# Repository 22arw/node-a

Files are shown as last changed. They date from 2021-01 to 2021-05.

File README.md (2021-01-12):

# Node-A Cruiser Maintenance Management for Wichita
## About this project
This project will improve cruiser maintenance tracking for the Wichita Police department. To better maintain our Wichita Police cruisers, an OBD-II compatible device connects to and monitors each cruiser. The device utilizes a LoRaWAN network within Wichita to send realtime notifications and data through gateways to a central server which can then be displayed on dashboards for the department. In order to utilize the LoRaWAN network, we’ll make use of the Protocol Buffers method of serializing data into small packets. We may divide the data into multiple packets sent periodically to meet the LoRaWAN duty cycle standard. Once the Server group has set up a network server, we’ll work to create a windows application that will display statistics from all cruisers and notify the maintenance department when maintenance is due. 
## Pinout
The pinout for the MKRCAN sheild, Adafruit Feather 32u4, ODB2 connector, and LED is listed below.

| DESC | MKRCAN | Feather | ODB2 | LED |
|---|---|---|---|-----|
| CAN CS | 3 | 6 | | |
| INT | 7 | SDA(1) | | |
| MOSI | 8 | MO | | |
| SCK | 9 | SCK | | |
| MISO | 10 | MI | | |
| CPU POWER | vcc | 3v | | |
| POWER TO F | vin | usb | | |
| POWER FROM F | 5v | usb | | |
| GND | GND | GND | | |
| LED GND | | GND | | GND |
| Red | | 9 | | R |
| Green | | 10 | | G |
| Blue | | 11 | | B |
| POWER FROM CAR | | 16 | VIN  | |
| CAR CAN | | 6 (CANH)  | CANL | |
| CAR CAN | | 14 (CANL) | CANH | |
| GND | | 5 | GND  | |

*The CAN library uses default CS and INT pins. To set different pins, use CAN.setPins(CS, INT).*

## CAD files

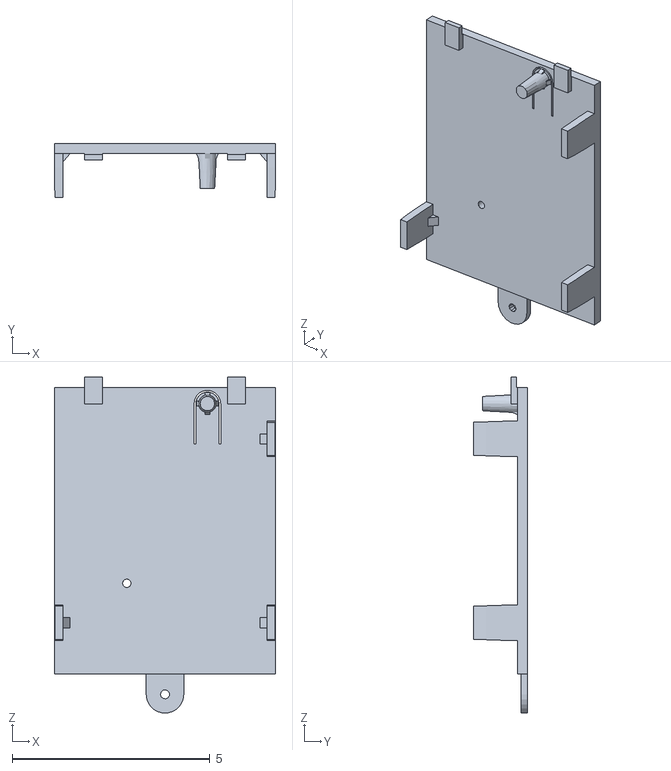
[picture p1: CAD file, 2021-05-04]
Inventor/housing.v.2.1/Top.stl
5.59 x 1.37 x 8.49

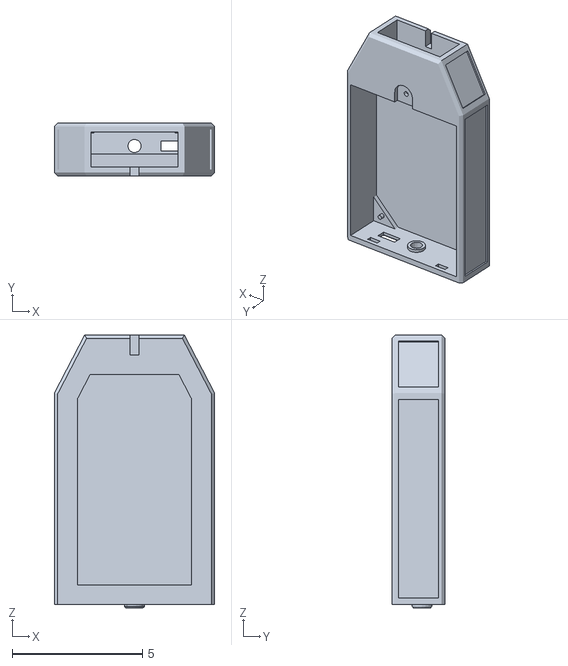
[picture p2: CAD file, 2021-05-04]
Inventor/housing.v.2.1/Bottom.stl
6.16 x 2.03 x 10.5

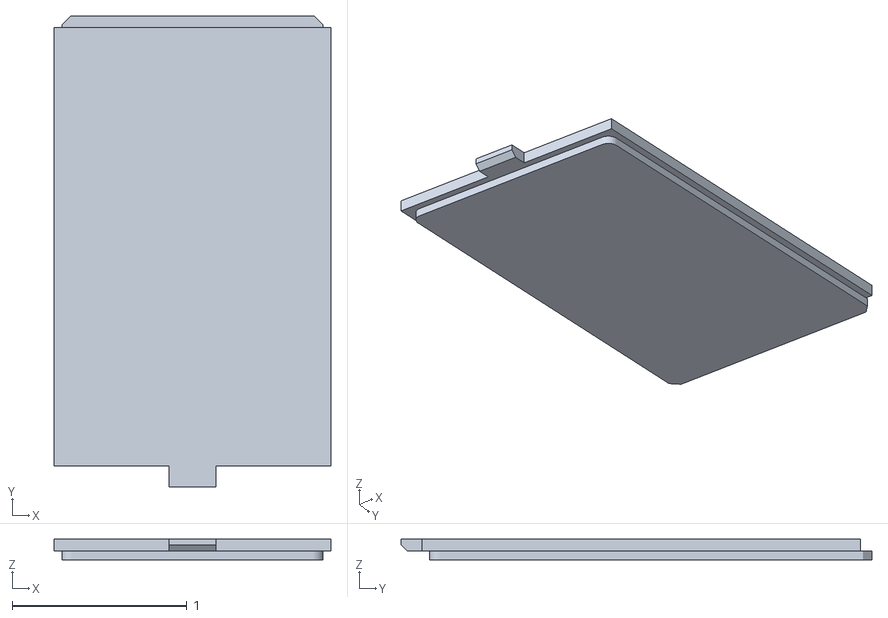
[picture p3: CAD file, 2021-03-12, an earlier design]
Inventor/housing.v.1/Main_Housing_Cap.stl
1.58 x 2.69 x 0.119

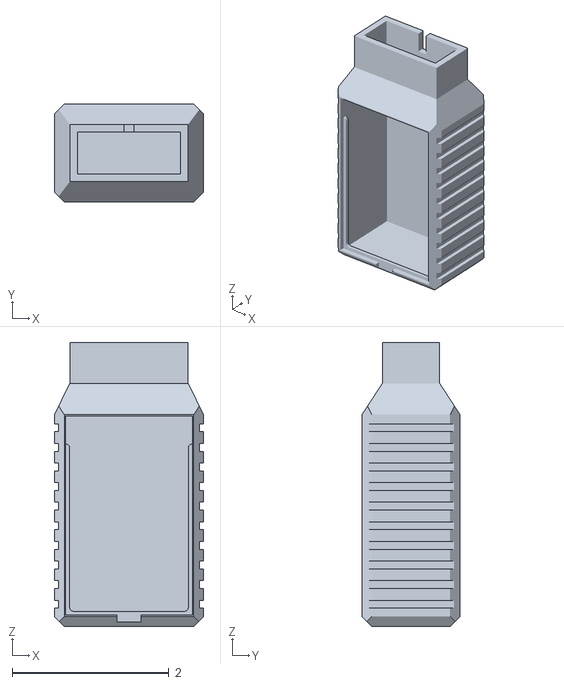
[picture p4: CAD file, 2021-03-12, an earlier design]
Inventor/housing.v.1/Main_Housing_Base.stl
1.90 x 1.25 x 3.62

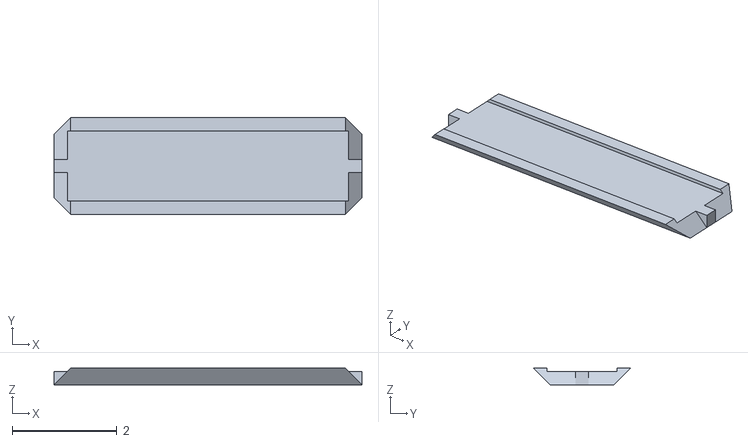
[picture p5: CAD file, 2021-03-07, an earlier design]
Inventor/housing.v.2/Cap.stl
5.89 x 1.85 x 0.317

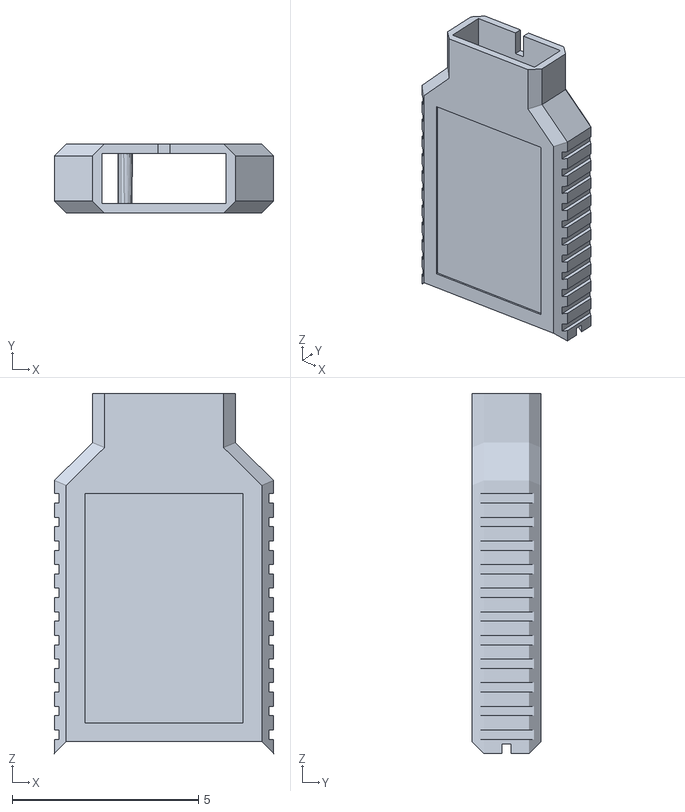
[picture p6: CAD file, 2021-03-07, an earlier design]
Inventor/housing.v.2/Shell.stl
5.89 x 1.85 x 9.68

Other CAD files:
Inventor/housing.v.1/Assembly1.iam
Inventor/housing.v.1/Main_Housing.ipt
Inventor/housing.v.1/Main_Housing_Base.ipt
Inventor/housing.v.1/Main_Housing_Cap.ipt
Inventor/housing.v.2.1/Assembly.iam
Inventor/housing.v.2.1/Bottom.ipt
Inventor/housing.v.2.1/OldVersions/Assembly.0002.iam
Inventor/housing.v.2.1/OldVersions/Bottom.0002.ipt
Inventor/housing.v.2.1/OldVersions/Top.0004.ipt
Inventor/housing.v.2.1/Top.ipt
Inventor/housing.v.2.1/WIP.ipt
Inventor/housing.v.2/Cap.ipt
Inventor/housing.v.2/Housing.iam
Inventor/housing.v.2/OldVersions/Cap.0001.ipt
Inventor/housing.v.2/OldVersions/Shell.0002.ipt
Inventor/housing.v.2/Shell.ipt

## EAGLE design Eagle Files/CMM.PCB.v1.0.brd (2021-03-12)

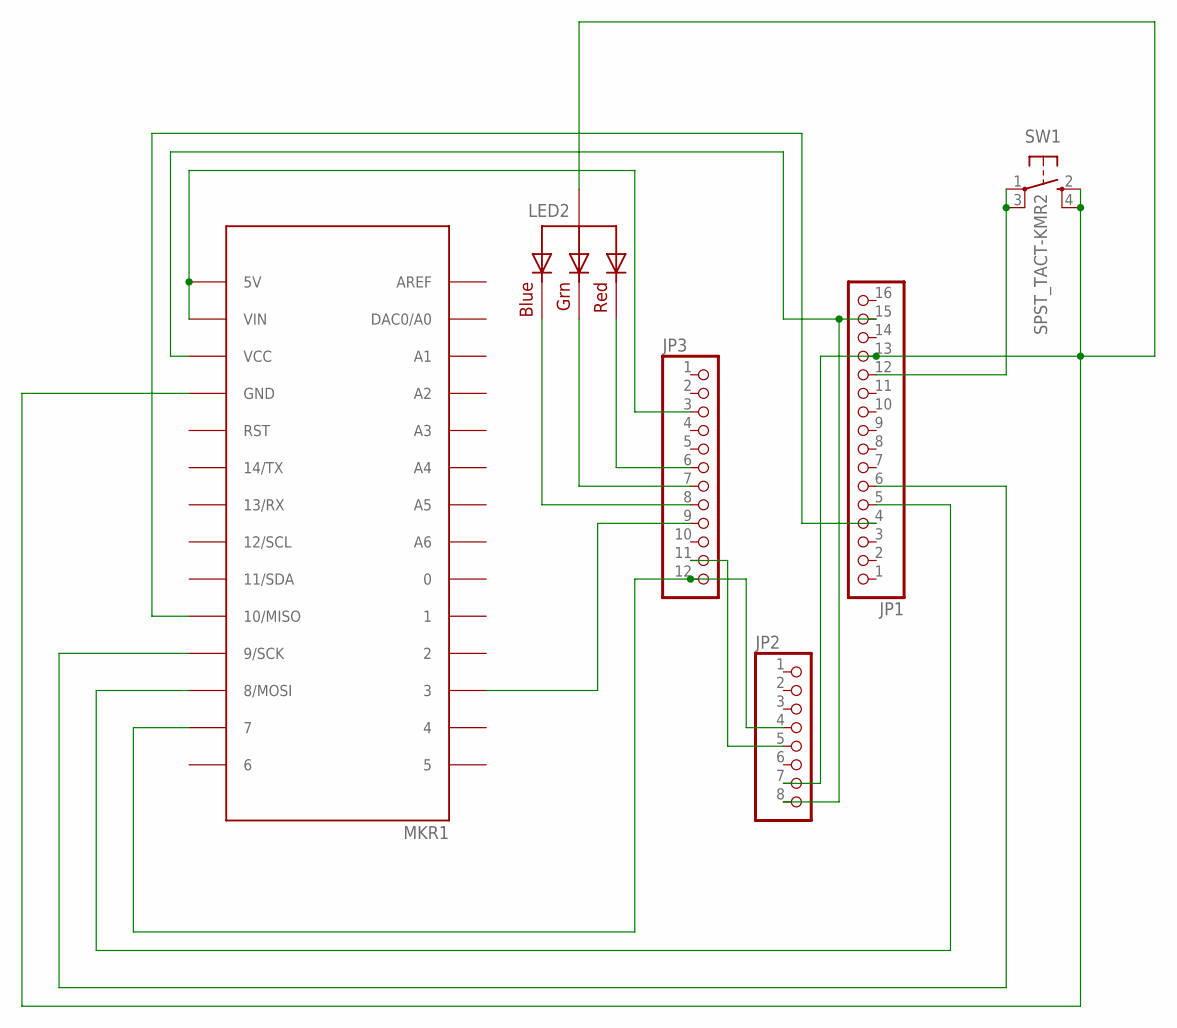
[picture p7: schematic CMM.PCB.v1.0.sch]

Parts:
JP1: HEADER-1X16ROUND; 1X16_ROUND
JP2: HEADER-1X870MIL; 1X08_ROUND_70
JP3: HEADER-1X12; 1X12_ROUND
LED2: RGBLED_CA-5MM; LED5MMRGB
MKR1: -; ARDUINO-UTILITY_MKRBOARD
SW1: SPST_TACT-KMR2; KMR2

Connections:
GND: JP1.13, JP2.7, LED2.2 (VCC), MKR1.GND, SW1.2 (S), SW1.4 (S1)
unnamed: JP3.9, MKR1.3
unnamed: JP2.4, JP3.12, MKR1.7
unnamed: JP1.5, MKR1.8 (8/MOSI)
unnamed: JP1.6, MKR1.9 (9/SCK)
unnamed: JP1.4, MKR1.10 (10/MISO)
unnamed: JP1.15, JP2.8, MKR1.VCC
unnamed: JP3.3, MKR1.5V, MKR1.VIN
unnamed: JP3.6, LED2.1 (RED)
unnamed: JP2.5, JP3.11
unnamed: JP3.7, LED2.3 (GREEN)
unnamed: JP3.8, LED2.4 (BLUE)
SIGNAL: JP1.12, SW1.1, SW1.3 (P1)

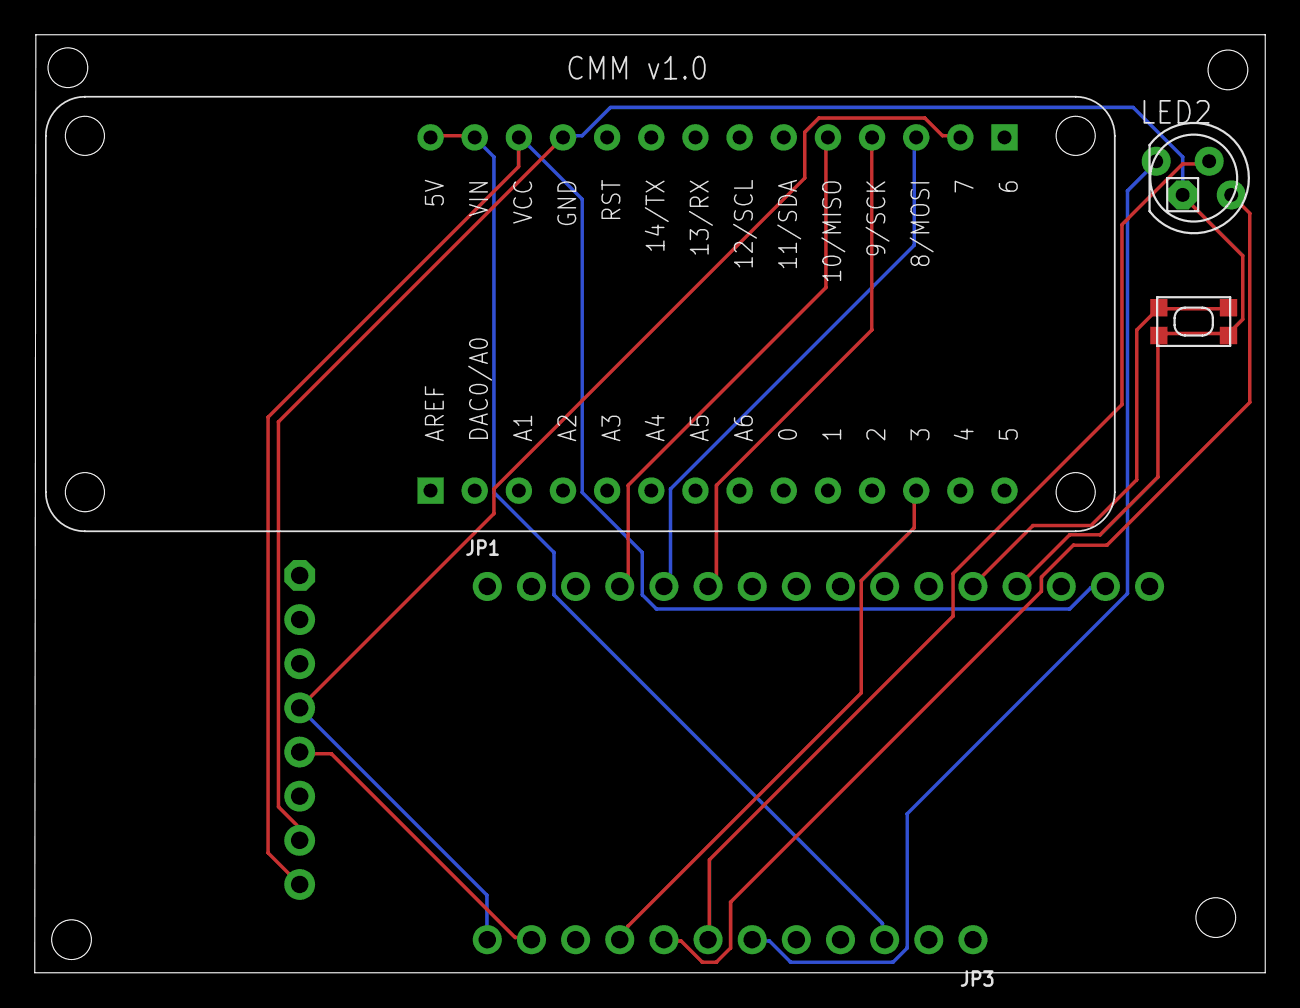
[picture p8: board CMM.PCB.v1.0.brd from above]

Board: 2 copper layers, 70.8 x 54.0 mm, 6 parts (0 on the bottom side), 13 nets.

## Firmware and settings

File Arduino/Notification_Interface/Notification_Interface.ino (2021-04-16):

#include <CAN.h>
#include <OBD2.h>
#include <jled.h>
#include <SPI.h>
#include <TinyLoRa.h>

// Network Session Key (MSB)
uint8_t NwkSkey[16] = { 0x19, 0x78, 0xb6, 0x13, 0x87, 0x6b, 0x6b, 0x1a, 0xee, 0xb1, 0x35, 0x65, 0xdd, 0xea, 0x39, 0x73 };


// Application Session Key (MSB)
uint8_t AppSkey[16] = { 0x5f, 0xb2, 0xe3, 0x39, 0xf2, 0x7b, 0x28, 0xcd, 0x93, 0x36, 0x91, 0xf2, 0x00, 0xde, 0xa5, 0x5a };

// Device Address (MSB)
uint8_t DevAddr[4] = { 0x00, 0x41, 0x23, 0x9a };


// for Feather32u4 RFM9x
#define RFM95_CS 8
#define RFM95_RST 4
#define RFM95_INT 7

TinyLoRa lora = TinyLoRa(RFM95_INT, RFM95_CS, RFM95_RST);


const int led_pin_r = 11;
const int led_pin_g = 9; //broken
const int led_pin_b = 10;

auto led = JLed(9);
unsigned long lastTime;



const int MAX_OBSERVERS = 10;

//int i = 0;
//bool flip = false;  
//float read_pid(uint8_t PID){
//  if(!flip) i++;
//  else i --;
//  if(i==15) flip = true;
//  return i;
//}

float read_pid(uint8_t pid){
  float pidValue = OBD2.pidRead(pid);
  if (isnan(pidValue)) {
    Serial.print("error");
  } else {
    // return valid pidValue
    return pidValue;
  }
}


//Holds observer settings and observations
struct Observer {
  uint16_t ID;
  bool active = false;
  int time_since_met = 0;
  int req_active_time;
  uint8_t PID;
  float req_value;
  int timeout;
  float peak_value;
  float avg_value;
  int count_since_met;
  bool compare_option; //Specify when req value is met. TRUE for actual>req_value, FALSE for actual<req_value
};

//Class for all things related to observing. Create and manage observers. 
class Observe_Class {
  public:
  Observer observers[MAX_OBSERVERS]; //Array of observers
  int observer_top = 0;  //maintain stack top to quickly add observers. 

  void add(uint16_t ID, uint8_t PID, float req_value, int req_active_time, int timeout, bool compare_option){
    observers[observer_top].ID = ID;
    observers[observer_top].PID = PID;
    observers[observer_top].req_value = req_value;
    observers[observer_top].req_active_time = req_active_time;
    observers[observer_top].timeout = timeout;
    observers[observer_top].compare_option = compare_option;
    observer_top++;
  }
  void edit(uint16_t ID, uint8_t PID, float req_value, int req_active_time, int timeout, bool compare_option){
    remove(ID);
    add(ID,PID, req_value, req_active_time, timeout, compare_option);
  }

  //remove observer. (observer removed in middle requires next observers to be shifted. 
  bool remove(uint16_t ID){
    bool found = false;
    for(int i = 0; i < observer_top; i ++){
      if(!found){
        if(observers[i].ID == ID) found = true;
      }
      else{
        observers[i-1] = observers[i];
      }
    }
    if(found) observer_top --;
    return found;
  }
  void update(){
    for(int i = 0; i < observer_top; i ++){
      float current_value = read_pid(observers[i].PID);
      long timePassed = millis() - lastTime;
      lastTime = millis();
      //if value meets required value. 
      if((current_value >= observers[i].req_value && observers[i].compare_option) 
      || (current_value <= observers[i].req_value && !observers[i].compare_option)){
        //set record value depending on compare option (greater/less than)
        if(observers[i].compare_option){
          if(current_value > observers[i].peak_value)
          observers[i].peak_value = current_value;
        }
        else{
          if(current_value < observers[i].peak_value)
          observers[i].peak_value = current_value;
        }

        //set average value with weight according to count_since_met
        observers[i].avg_value = 
       (observers[i].avg_value * observers[i].count_since_met + current_value)/(++observers[i].count_since_met);

        //make active if req value has been met for float enough
        if(!observers[i].active){
          if(observers[i].time_since_met >= observers[i].req_active_time){
            observers[i].active = true;
          }
        }
        else{
          //check if timeout should take place. Send notification if so. 
          if(observers[i].time_since_met >= observers[i].timeout){
            notify(observers[i].ID,observers[i].peak_value, observers[i].avg_value);
            observers[i].active = false;
            observers[i].time_since_met = 0;
            observers[i].count_since_met = 0;
            observers[i].peak_value = 0;
          }
        }
        
        //increase time since met
        observers[i].time_since_met += (timePassed/1000); //add real-time to time_since_met
      }
      else{//values out of range. 
        
        //if notification was being recorded. 
        if(observers[i].active){
        observers[i].active = false;
        notify(observers[i].ID,observers[i].peak_value, observers[i].avg_value);
        }
        //reset time since met
        observers[i].time_since_met = 0;
        observers[i].count_since_met = 0;
        observers[i].peak_value = 0;
        
      }
    }
  }

  
};

Observe_Class observe;

typedef union {
  unsigned long longFormat;
  float floatFormat;
}ByteFloatUnion;

void notify(uint16_t ID, float val1, float val2){
  unsigned char loraData[10];

  //Store float as long (not the same as casting, as this would round)
  ByteFloatUnion byteVal1;
  ByteFloatUnion byteVal2;
  
  byteVal1.floatFormat = val1;
  byteVal2.floatFormat = val2;
  
  loraData[0] = lowByte(ID); //0A
  loraData[1] = highByte(ID); //00
  loraData[2] = (byteVal1.longFormat) & 0xff;
  loraData[3] = (byteVal1.longFormat>>8) & 0xff;
  loraData[4] = (byteVal1.longFormat>>16) & 0xff;
  loraData[5] = (byteVal1.longFormat>>24) & 0xff;
  loraData[6] = (byteVal2.longFormat) & 0xff;
  loraData[7] = (byteVal2.longFormat>>8) & 0xff;
  loraData[8] = (byteVal2.longFormat>>16) & 0xff;
  loraData[9] = (byteVal2.longFormat>>24) & 0xff;
 
  lora.sendData(loraData, sizeof(loraData), lora.frameCounter);
  lora.frameCounter++;
  String str_msg;
  str_msg += (String)ID;
  str_msg += " ";
  str_msg += (String) val1;
  str_msg += " ";
  str_msg += (String) val2;
  char message[30];
  str_msg.toCharArray(message,30);
  Serial.println(message);
  {
    led = JLed(led_pin_r).Blink(300,300).Repeat(2);
  }
}



//process string based commands. 
bool run_command(char command[30]){
  //tokenize command for argument passing
  byte index = 0;
  char *p[30];
  char *ptr = NULL;
  ptr = strtok(command, ":;,\n");
  
  while(ptr!=NULL){
    p[index] = ptr;
    index++;
    ptr =  strtok(NULL, ":;,\n");
  }

  switch (*p[0]) {
  case 'A': //add observver
    Serial.println("Add");
    observe.add(atoi(p[1]),atoi(p[2]),atof(p[3]),atoi(p[4]),atoi(p[5]),p[6]!=0);
    break;
  case 'E': //edit observer
    Serial.println("Edit");
    observe.edit(atoi(p[1]),atoi(p[2]),atof(p[3]),atoi(p[4]),atoi(p[5]),p[6]!=0);
    break;
  case 'D': //delete observer
    Serial.println("Delete");
    observe.remove(atoi(p[1]));
    break;
  case 'P': //print PID
    int PID = atoi(p[1]);
    float PID_val = read_pid(PID);
    notify(0,PID, PID_val); //send pid notification
    break;
  default:
    Serial.println("Invalid command");
    break;
}

}

//get commands, if any
void get_commands(){

  //get array of characters from serial if available
  char command[30];
  int i = 0;
  if(Serial.available() > 0){
    while(Serial.available()){
      delay(2);
      command[i] = Serial.read();
      i++;
    }
    command[i] = '\0';
    run_command(command);
  }

  //Commands over LoraWAN not supported.
  
}

void setup() {
  // initialize serial at 9600 baud
  Serial.begin(9600);
  //while (!Serial);

    // Initialize LoRa
  Serial.print("Starting LoRa...");
  // define channel to send data on
  lora.setChannel(CH2);
  // set datarate
  lora.setDatarate(SF7BW125);
    if(!lora.begin())
  {
    Serial.println("Failed");
    Serial.println("Check your radio");
    while(true);
  }
  Serial.println("LoRa Ready!");
 
  
  //connect to can
  while (false) {
    Serial.print(F("Attempting to connect to OBD2 CAN bus ... "));
    CAN.setPins(6,2);
    if (!OBD2.begin()) {
      Serial.println(F("failed!"));
      delay(1000);
    } 
    else {
      led = JLed(led_pin_b).On();
      led.Update();
      Serial.println(F("success"));
      break;
    }
  }
  Serial.println();
}

//main loop
void loop() {
  //get_commands();
  //led.Update();
  //observe.update();
  float val1 = 0.0000000001;
  float val2 = 100002;
  int ID = 10;
  notify(ID, val1, val2);
  delay(20000);
}

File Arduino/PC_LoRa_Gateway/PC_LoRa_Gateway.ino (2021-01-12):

// Feather9x_TX
// -*- mode: C++ -*-
// Example sketch showing how to create a simple messaging client (transmitter)
// with the RH_RF95 class. RH_RF95 class does not provide for addressing or
// reliability, so you should only use RH_RF95 if you do not need the higher
// level messaging abilities.
// It is designed to work with the other example Feather9x_RX

#include <SPI.h>
#include <RH_RF95.h>

//for feather32u4 
#define RFM95_CS 8
#define RFM95_RST 4
#define RFM95_INT 7


// Change to 434.0 or other frequency, must match RX's freq!
#define RF95_FREQ 915.0

// Singleton instance of the radio driver
RH_RF95 rf95(RFM95_CS, RFM95_INT);

void setup() 
{
  pinMode(RFM95_RST, OUTPUT);
  digitalWrite(RFM95_RST, HIGH);

  Serial.begin(9600);
//  while (!Serial) {
//    delay(1);
//  }

  delay(100);

  Serial.println("Feather LoRa TX Test!");

  // manual reset
  digitalWrite(RFM95_RST, LOW);
  delay(10);
  digitalWrite(RFM95_RST, HIGH);
  delay(10);

  while (!rf95.init()) {
    Serial.println("LoRa radio init failed");
    Serial.println("Uncomment '#define SERIAL_DEBUG' in RH_RF95.cpp for detailed debug info");
    while (1);
  }
  Serial.println("LoRa radio init OK!");

  // Defaults after init are 434.0MHz, modulation GFSK_Rb250Fd250, +13dbM
  if (!rf95.setFrequency(RF95_FREQ)) {
    Serial.println("setFrequency failed");
    while (1);
  }
  Serial.print("Set Freq to: "); Serial.println(RF95_FREQ);
  
  // Defaults after init are 434.0MHz, 13dBm, Bw = 125 kHz, Cr = 4/5, Sf = 128chips/symbol, CRC on

  // The default transmitter power is 13dBm, using PA_BOOST.
  // If you are using RFM95/96/97/98 modules which uses the PA_BOOST transmitter pin, then 
  // you can set transmitter powers from 5 to 23 dBm:
  rf95.setTxPower(23, false);
}

 
void Local_TX(char message[]){
    Serial.print("Sending "); Serial.println(message);
    delay(10);
    rf95.send((uint8_t *)message, 20);

    delay(10);
    rf95.waitPacketSent();
    Serial.println("Sent!");
}

void Print_RX(){
 if (rf95.available())
  {
    // Should be a message for us now
    uint8_t buf[RH_RF95_MAX_MESSAGE_LEN];
    uint8_t len = sizeof(buf);

    if (rf95.recv(buf, &len))
    {
      RH_RF95::printBuffer("Received: ", buf, len);
      Serial.print("Got: ");
      Serial.println((char*)buf);
       Serial.print("RSSI: ");
      Serial.println(rf95.lastRssi(), DEC);
    }
    else
    {
      Serial.println("Receive failed");
    }
  }
}

char command[30];
void loop()
{
  Print_RX(); //print if any RX 
  
  if(Serial.available() > 0){
    int i = 0;
    while(Serial.available()){
      delay(2);
      command[i] = Serial.read();
      i++;
    }
    command[i] = '\0';
    Local_TX(command);
  }
}

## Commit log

2021-01-12 Initial despot of code written last semester.
    This includes the car-device firmware and our development lora-serial relay code.
2021-03-03 Update Corrected Schematic and Board files
    [CMM.PCB.v1.0.brd, CMM.PCB.v1.0.sch]
2021-03-03 Change folder name
    [CMM.PCB.v1.0.brd, CMM.PCB.v1.0.sch]
2021-03-07 Built housing shell and cap.
    [Cap.0001.ipt, Cap.ipt, Cap.stl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]
2021-03-12 Board and Schematic files
    [CMM.PCB.v1.0.brd, CMM.PCB.v1.0.sch]
2021-03-12 Added first semester housing.
    [Assembly1.iam, Cap.0001.ipt, Cap.ipt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]
2021-04-06 Create internal gateway frame export.json
2021-04-06 Range testing sample code
2021-04-16 Finished encoder / decoder testing
2021-05-04 Added new housing.
    [Assembly.0002.iam, Assembly.iam, Bottom.0002.ipt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]

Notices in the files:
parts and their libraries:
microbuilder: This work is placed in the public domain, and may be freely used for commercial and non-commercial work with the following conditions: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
